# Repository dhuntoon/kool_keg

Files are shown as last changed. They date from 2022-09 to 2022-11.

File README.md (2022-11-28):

# Kool Keg
Purdue University > ECE Senior Design (ECE 49022) > Lab Section 5 > Team 51

This repository holds relevant files for Team 51 (_Kool Keg_) in ECE Senior Design. It includes hardware schematics, PCB layouts, mobile application software, and software diagrams.

## Table of Contents

kool_keg (repository home directory)

* `/Circuit Design/...`
  * system hardware schematics
  
* `/main/...`
  * Software for MCU
 
* `/Kool Keg Circuit/...`
  * PCB Design and related files for system hardware

* `/Software/...`
  * Software subsystem working directory
  * `/aws_backend/...`
    * sub-directory contianing AWS Lambda code . 
    * This code is mirrored manually for reference and is **not** executed directly from this source.
    * **This directory holds code written by Dylan Huntoon for the subsystem**
  * `/figures/`...
    * sub-directory containing software flow diagrams and subsystem block diagram(s)
    * **This directory holds figures created by Dylan Huntoon for the subsystem**
  * `/keg_app/...`
    * sub-directory containing code related to the mobile app (Flutter SDK and dependencies)
    * `/lib/...`
      * sub-directory containing Flutter (Dart) code for the mobile app
      * **This directory holds code written by Dylan Huntoon for the subsystem**
  * `/testing_scripts/...` 
    * sub-directory containing Python code and JSON output for testing the software_subsystem
    * **This directory holds code written by Dylan Huntoon for the subsystem**
 
* `/README.md`
  * this markdown file

## Software Design

### Subsystem Block Diagram
The following diagram illustrates the components of the software subsystem and related interactions with other subsystems. The color-coding corresponds to the overall system diagram, found in the design documentation.

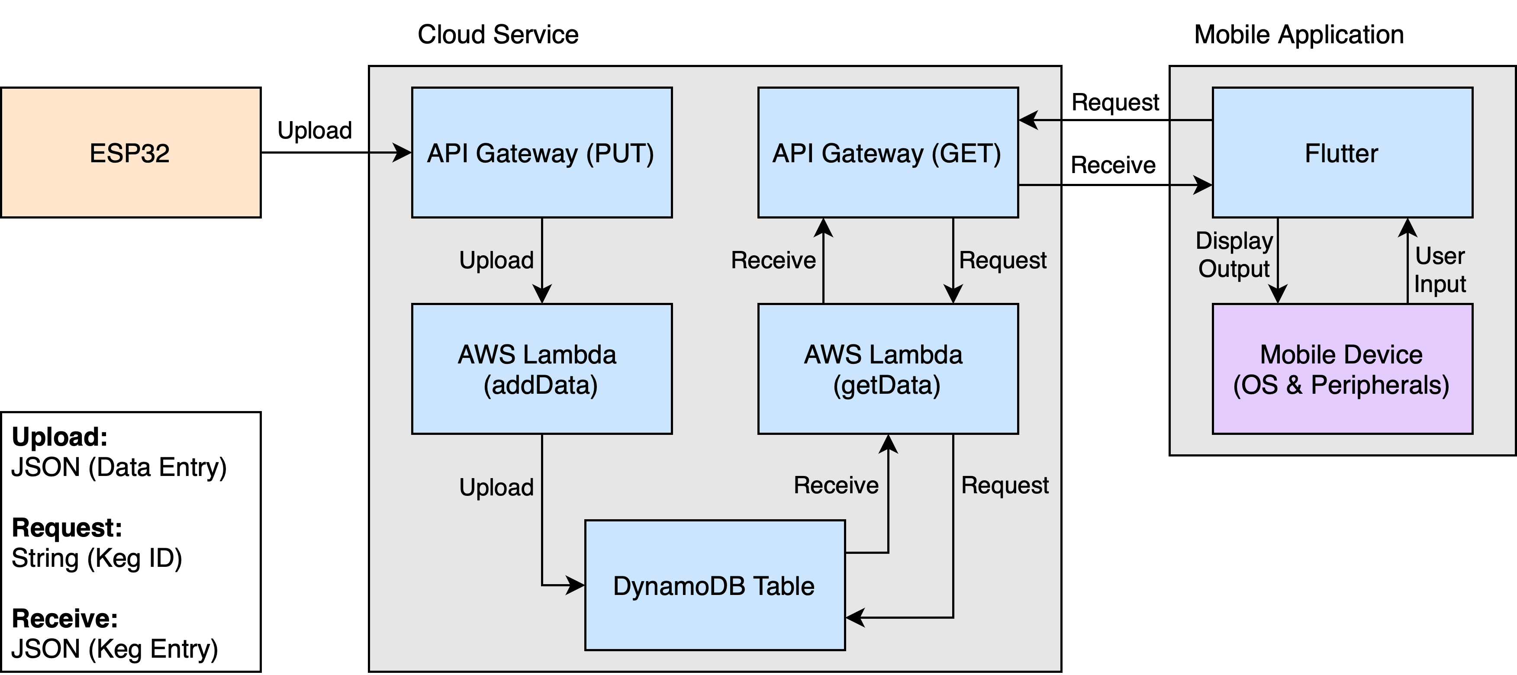
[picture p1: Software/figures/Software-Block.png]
Block Diagram


### Subsystem Software Architecture
The following diagram illustrates the software architecture for the system's mobile application. The program is written in Flutter (Dart) and is deployable on iOS and Android platforms. The black circle identifies the program entry point and is triggered when the application launches. 

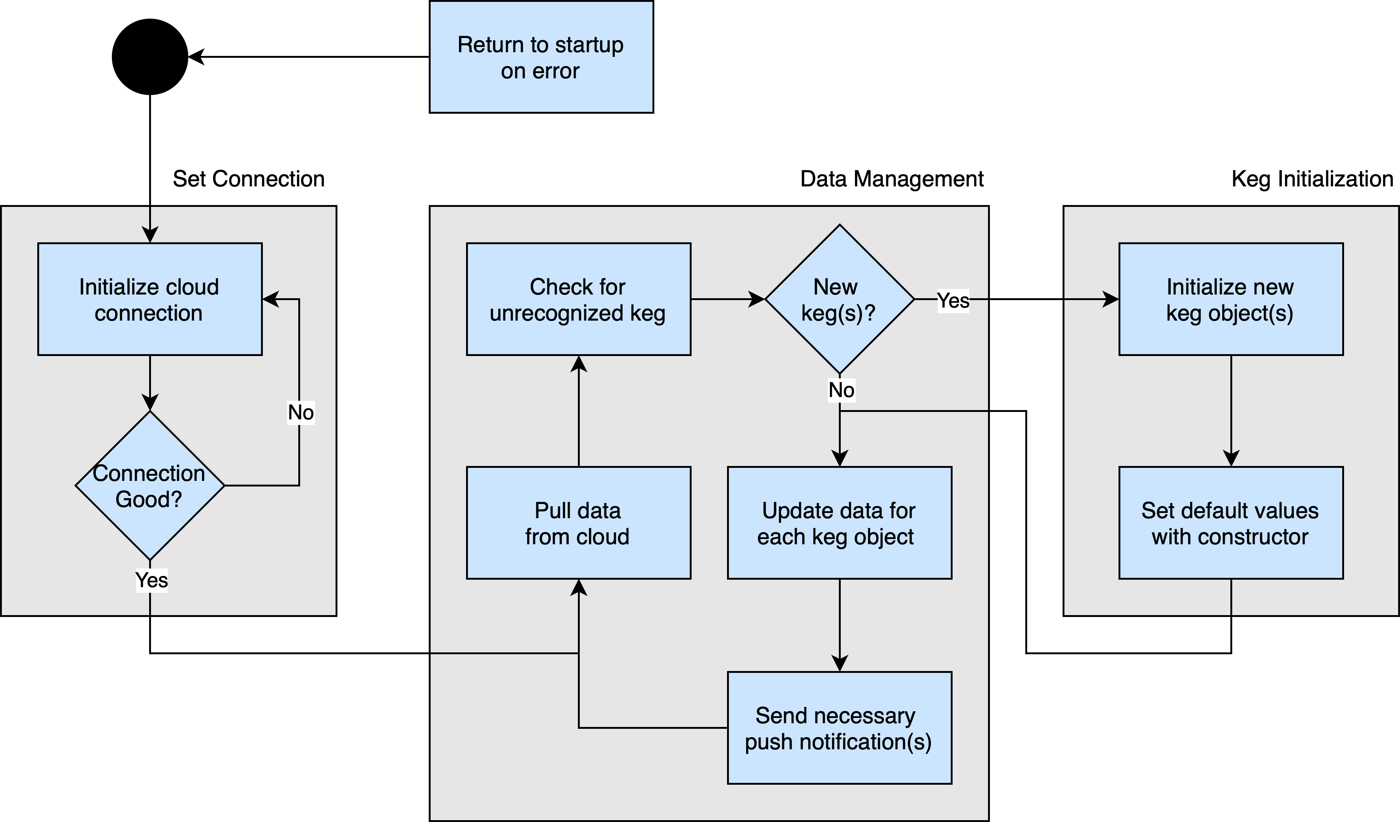
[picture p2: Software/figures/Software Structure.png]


For further detail, see the related figures in the `Software/figures/` subdirectory.

## Operating the Mobile App

Updated Nov 1, 2022.

The mobile application will be deployed onto devices supporting the iOS and Android platforms. Execution will automatically begin when the application is launched on the aforementioned devices.

To build or prototype with the program on a local machine, you must install the following dependencies. To ensure dependencies are installed correctly, reference the flutter documentation (https://docs.flutter.dev/get-started/install).

Dependencies:
* Flutter (Flutter SDK 3.3.1)
* Android toolchain (Android SDK version 33.0.0)
* Xcode (Xcode 14.0) - for building and emulating iOS applications
* Android Studio (version 2021.2) - for emulating Android applications

For rapid prototyping and testing, an IDE (such as VSCode or XCode) is recommended. Alternative command line operations are listed below for Unix terminals. 

### Command Line Operations

See the following documentation for Flutter Command Line Tools: https://docs.flutter.dev/reference/flutter-cli.

```$ flutter --version``` returns the version of flutter installed on your machine. 

```$ flutter doctor``` returns the dependency checks for the aforementioned libraries. Helpful installation directions are provided for missing dependencies. 

To build the program:
```
$ cd kool_keg/Software/keg_app
$ flutter build target
```
where `target` is the targeted platform (ios, android, etc.)

To run the program:
```
$ cd kool_keg/Software/keg_app
$ flutter run lib/main.dart
```

## Credits

Contributors to this repository:
* Cole Kniffen (ckniffen@purdue.edu)
* Dylan Huntoon (dhuntoon@purdue.edu)
* Mitchell Morris (morri448@purdue.edu)
* Jared Nutt (nuttj@purdue.edu)

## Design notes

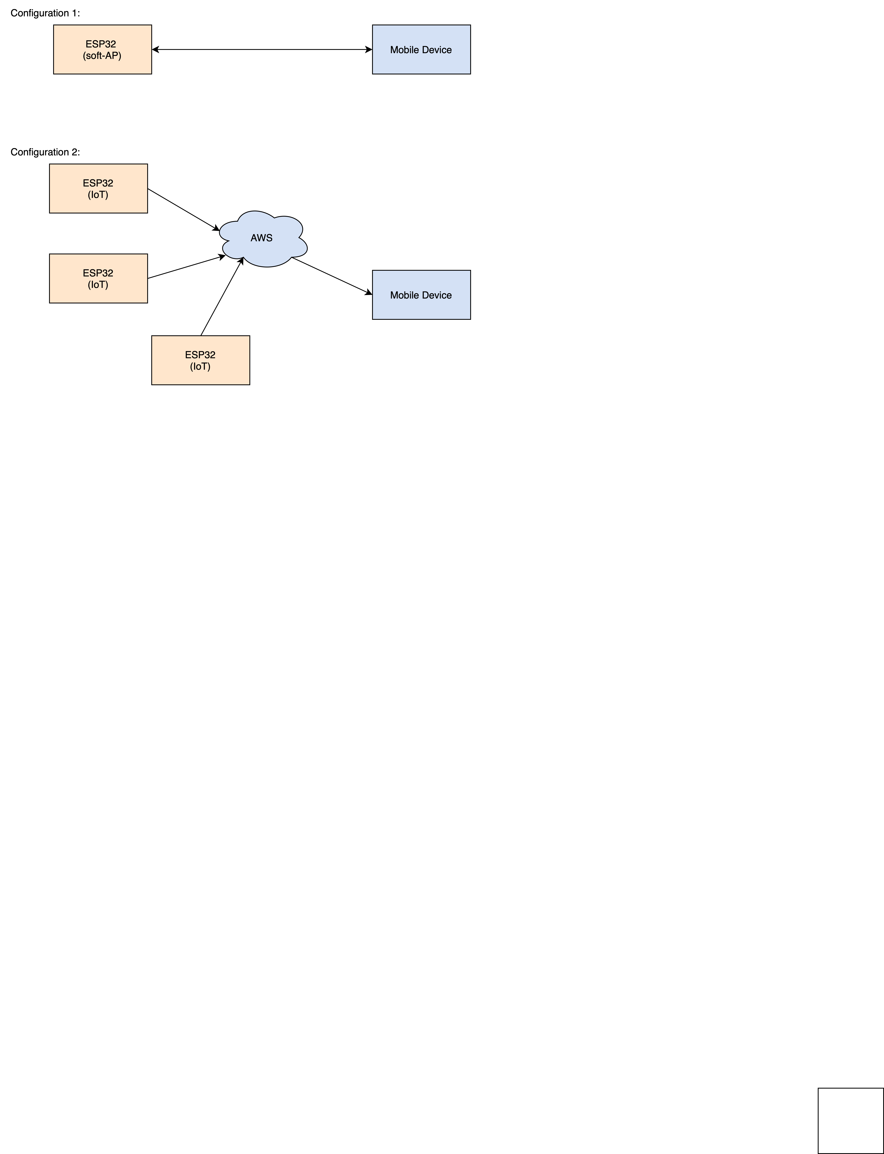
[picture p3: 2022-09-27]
Software/design/cloud_vs_direct_ configs.png

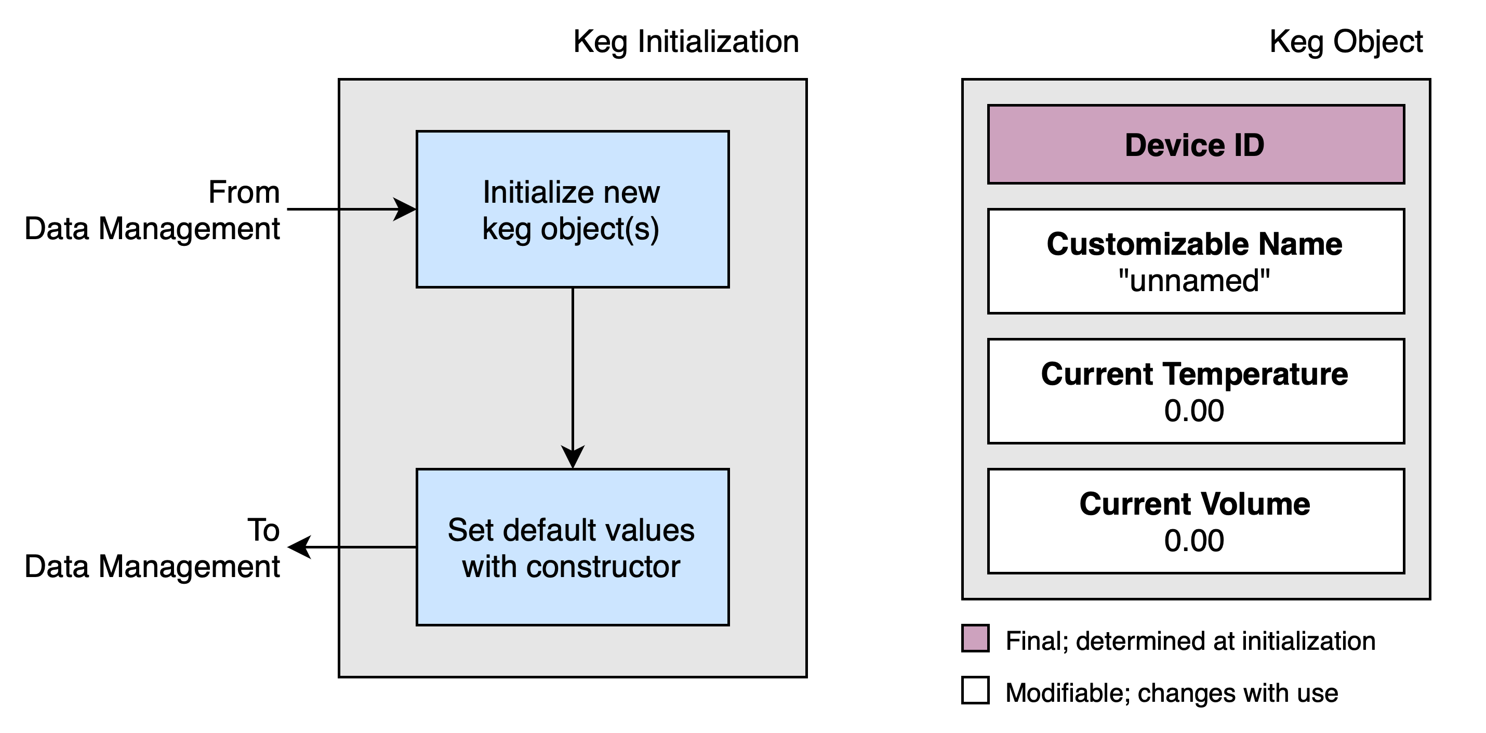
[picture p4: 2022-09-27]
Software/design/Object Structure.png

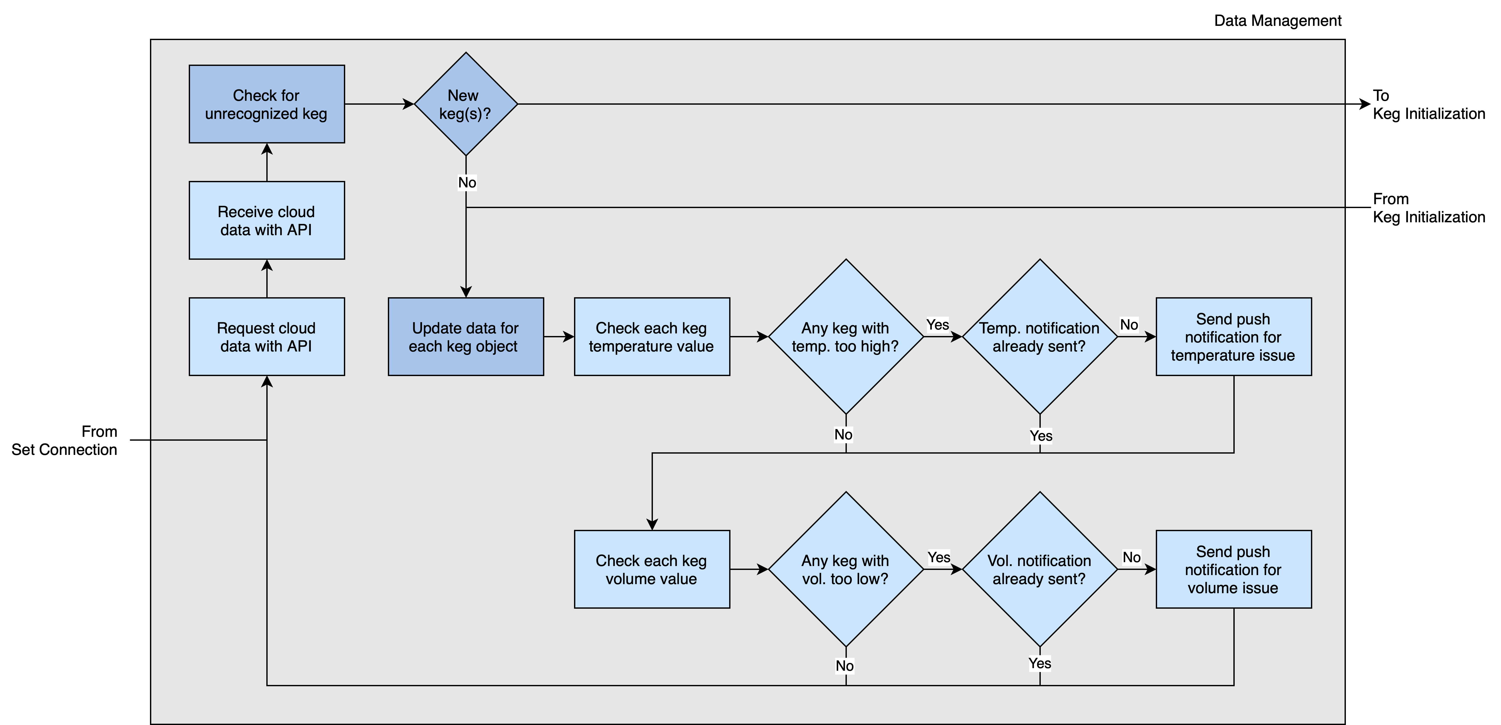
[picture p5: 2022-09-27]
Software/design/Data Management.png

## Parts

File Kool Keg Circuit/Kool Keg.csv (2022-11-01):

Source: | /Users/ckniffen/Desktop/Senior Design/kool_keg/Kool Keg Circuit/Kool Keg.kicad_sch
Date: | Tuesday, November 01, 2022 at 11:46:51 AM
Tool: | Eeschema (6.0.7-1)-1
Generator: | /Applications/KiCad/KiCad.app/Contents/SharedSupport/plugins/bom_csv_grouped_by_value_with_fp.py
Component Count: | 68
Ref | Qnty | Value | Cmp name | Footprint | Description | Vendor
C1, | 1 | 100nF | C | Capacitor_SMD:C_0805_2012Metric_Pad1.18x1.45mm_HandSolder | Unpolarized capacitor
C2, | 1 | 10uF | C | Capacitor_SMD:CP_Elec_4x5.8 | Unpolarized capacitor
C3, | 1 | 68nF | C | Capacitor_SMD:C_0805_2012Metric_Pad1.18x1.45mm_HandSolder | Unpolarized capacitor
C4, C5, C15, C17, | 4 | 10uF | CAP | Capacitor_SMD:C_0805_2012Metric_Pad1.18x1.45mm_HandSolder | Capacitor symbol for simulation only
C6, | 1 | .1uF | C | Capacitor_SMD:C_0603_1608Metric_Pad1.08x0.95mm_HandSolder | Unpolarized capacitor
C7, | 1 | 100uF | C | Capacitor_SMD:CP_Elec_6.3x5.8 | Unpolarized capacitor
C8, | 1 | 56pF | C | Capacitor_SMD:C_0603_1608Metric_Pad1.08x0.95mm_HandSolder | Unpolarized capacitor
C9, C10, C22, | 3 | 22uF | C_Small | Capacitor_SMD:C_0805_2012Metric_Pad1.18x1.45mm_HandSolder | Unpolarized capacitor, small symbol
C11, C12, C13, C14, C16, C23, | 6 | 0.1uF | C_Small | Capacitor_SMD:C_0805_2012Metric_Pad1.18x1.45mm_HandSolder | Unpolarized capacitor, small symbol
C18, | 1 | 2.2uF | C_Small | Capacitor_SMD:C_0805_2012Metric_Pad1.18x1.45mm_HandSolder | Unpolarized capacitor, small symbol
C19, C21, | 2 | .1uF | C_Small | Capacitor_SMD:C_0805_2012Metric_Pad1.18x1.45mm_HandSolder | Unpolarized capacitor, small symbol
C20, | 1 | 100 nF | C_Small | Capacitor_SMD:C_0805_2012Metric_Pad1.18x1.45mm_HandSolder | Unpolarized capacitor, small symbol
D1, D2, D3, | 3 | D | D | Diode_SMD:D_0805_2012Metric_Pad1.15x1.40mm_HandSolder | Diode
D4, | 1 | 1N4148 | 1N4148 | Diode_THT:D_DO-35_SOD27_P7.62mm_Horizontal | 100V 0.15A standard switching diode, DO-35
J1, | 1 | Conn_01x02_Male | Conn_01x02_Male | Connector_Molex:Molex_KK-396_A-41791-0002_1x02_P3.96mm_Vertical | Generic connector, single row, 01x02, script generated (kicad-library-utils/schlib/autogen/connector/)
J2, | 1 | Scale Header | Conn_01x04_Male | Connector_PinHeader_2.00mm:PinHeader_1x04_P2.00mm_Vertical | Generic connector, single row, 01x04, script generated (kicad-library-utils/schlib/autogen/connector/)
J3, | 1 | IR Header | Conn_01x04_Male | Connector_PinHeader_2.00mm:PinHeader_1x04_P2.00mm_Vertical | Generic connector, single row, 01x04, script generated (kicad-library-utils/schlib/autogen/connector/)
J4, | 1 | Flowmeter Header | Conn_01x03_Male | Connector_PinHeader_2.00mm:PinHeader_1x03_P2.00mm_Vertical | Generic connector, single row, 01x03, script generated (kicad-library-utils/schlib/autogen/connector/)
J5, | 1 | Prog | Conn_01x06_Male | Connector_PinHeader_2.00mm:PinHeader_1x06_P2.00mm_Vertical | Generic connector, single row, 01x06, script generated (kicad-library-utils/schlib/autogen/connector/)
J6, | 1 | Solenoid Conn, 01x02_Male | Conn_01x02_Male | Connector_Molex:Molex_KK-396_A-41791-0002_1x02_P3.96mm_Vertical | Generic connector, single row, 01x02, script generated (kicad-library-utils/schlib/autogen/connector/)
J7, | 1 | Conn_01x02_Female | Conn_01x04_Female | Connector_PinHeader_2.00mm:PinHeader_1x04_P2.00mm_Vertical | Generic connector, single row, 01x04, script generated (kicad-library-utils/schlib/autogen/connector/)
L1, | 1 | 3.3uH | L | Inductor_SMD:L_Bourns_SRN6045TA | Inductor
Q1, | 1 | 2N3905 | 2N3905 | Package_TO_SOT_THT:TO-92_Inline | -0.2A Ic, -40V Vce, Small Signal PNP Transistor, TO-92
Q2, | 1 | 2N3906 | 2N3906 | Package_TO_SOT_THT:TO-92_Inline | -0.2A Ic, -40V Vce, Small Signal PNP Transistor, TO-92
R1, | 1 | 330 | R | Resistor_SMD:R_0805_2012Metric_Pad1.20x1.40mm_HandSolder | Resistor
R2, | 1 | 1k | R | Resistor_SMD:R_0805_2012Metric_Pad1.20x1.40mm_HandSolder | Resistor
R3, | 1 | 30.9k | R | Resistor_SMD:R_0805_2012Metric_Pad1.20x1.40mm_HandSolder | Resistor
R4, R16, R17, R18, R19, R20, R21, | 7 | 10k | R | Resistor_SMD:R_0805_2012Metric_Pad1.20x1.40mm_HandSolder | Resistor
R5, R6, R7, R8, R9, R10, | 6 | 22000 | R | Resistor_SMD:R_0805_2012Metric_Pad1.20x1.40mm_HandSolder | Resistor
R11, R12, | 2 | 100 | R | Resistor_SMD:R_0805_2012Metric_Pad1.20x1.40mm_HandSolder | Resistor
R13, | 1 | 8.2k | R | Resistor_SMD:R_0805_2012Metric_Pad1.20x1.40mm_HandSolder | Resistor
R14, | 1 | 22k | R | Resistor_SMD:R_0805_2012Metric_Pad1.20x1.40mm_HandSolder | Resistor
R15, | 1 | 100k | R_Small | Resistor_SMD:R_0805_2012Metric_Pad1.20x1.40mm_HandSolder | Resistor, small symbol
SW1, SW2, SW3, | 3 | SW_MEC_5G | SW_Push | Button_Switch_THT:SW_PUSH-12mm | Push button switch, generic, two pins
U1, | 1 | LM1117-ADJ | LM1117-ADJ | Package_TO_SOT_SMD:SOT-223-3_TabPin2 | 800mA Low-Dropout Linear Regulator, adjustable output, TO-220/TO-252/TO-263/SOT-223
U2, | 1 | TPS562207 | TPS562200 | Package_TO_SOT_SMD:SOT-563 | 2A Synchronous Step-Down Voltage Regulator, Adjustable Output Voltage, 4.5-17V Input Voltage, SOT-23-6
U3, | 1 | 74LVC3G14 | 74LVC3G14 | Package_SO:MSOP-8_3x3mm_P0.65mm | Triple NOT Gate Schmitt, Low-Voltage CMOS
U4, | 1 | HX711 | HX711_1 | Package_SO:SOP-16_3.9x9.9mm_P1.27mm
U5, | 1 | 946-MPQ6610GS-AEC1-P | 946-MPQ6610GS-AEC1-P | Package_SO:SOIC-8_3.9x4.9mm_P1.27mm
U6, | 1 | 24LC256-I/MS | 24LC256 | Package_SO:MSOP-8_3x3mm_P0.65mm | I2C Serial EEPROM, 256Kb, DIP-8/SOIC-8/TSSOP-8/DFN-8
U7, | 1 | ESP32-WROOM-32D | ESP32-WROOM-32D | RF_Module:ESP32-WROOM-32 | RF Module, ESP32-D0WD SoC, Wi-Fi 802.11b/g/n, Bluetooth, BLE, 32-bit, 2.7-3.6V, onboard antenna, SMD

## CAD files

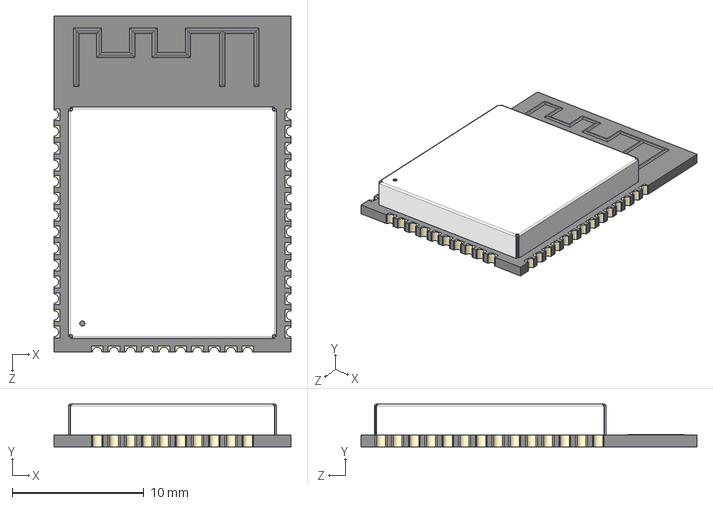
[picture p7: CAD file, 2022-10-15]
Kool Keg Circuit/ESP32-WROOM-32D/ESP32-WROOM-32D.step
18.0 x 3.25 x 25.5 mm

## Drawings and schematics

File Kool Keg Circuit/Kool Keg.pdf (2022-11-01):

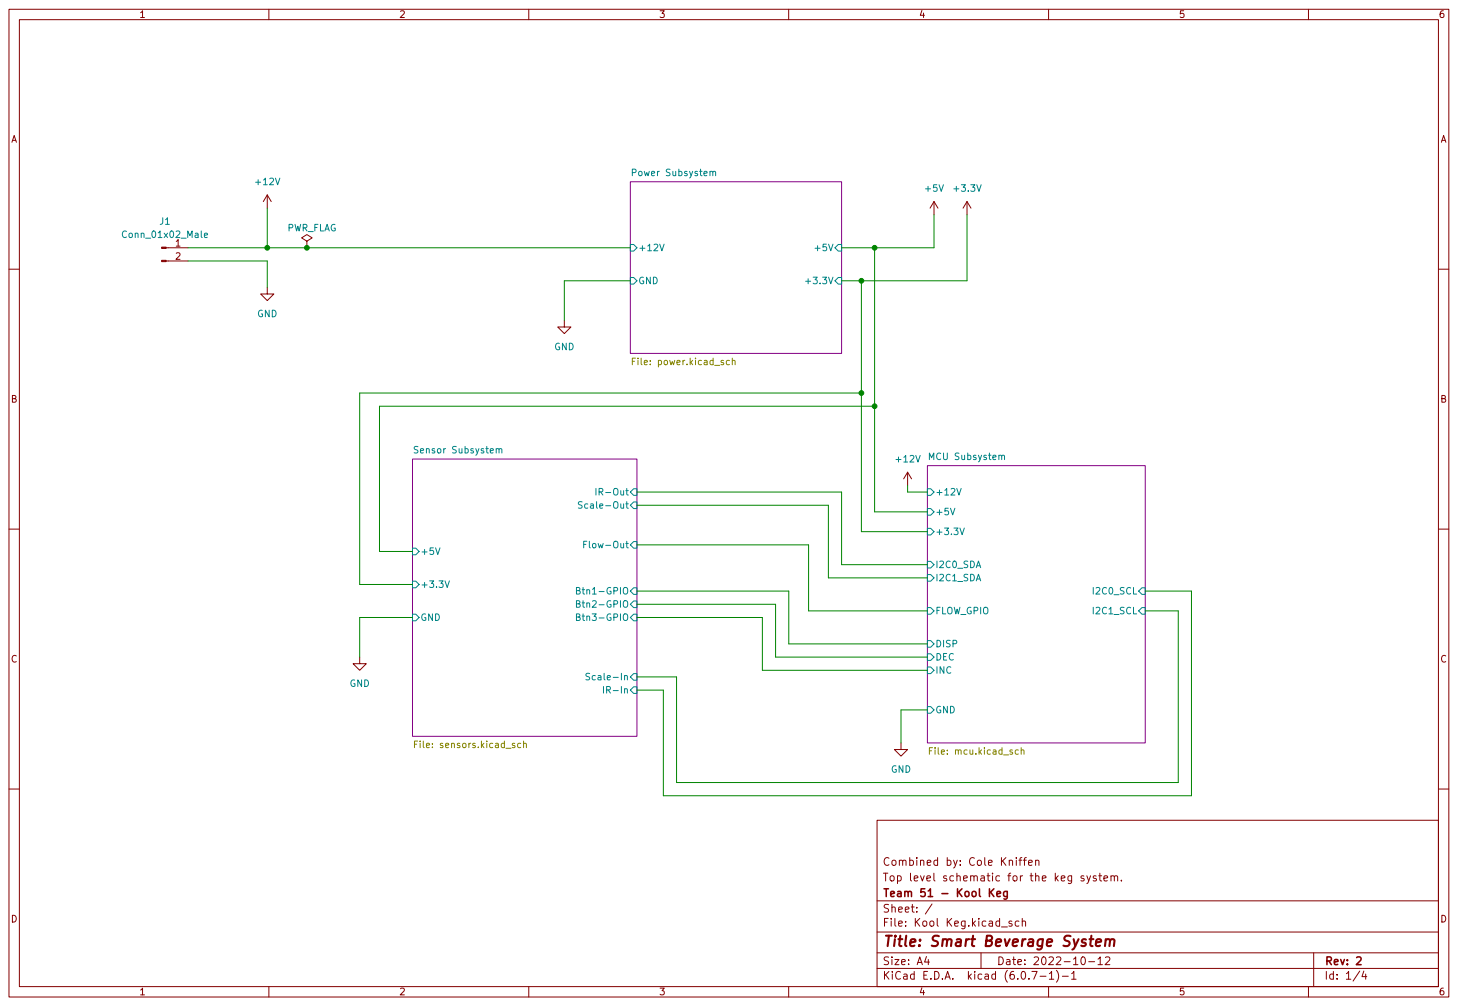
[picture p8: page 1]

Scale-Out Scale-In Sensor Subsystem

IR-Out Flow-Out Btn1-GPIO

Combined by: Cole Kniffen
Top level schematic for the keg system.
File: Kool Keg.kicad_sch Sheet: / Team 51 - Kool Keg

Id: 1/4 Title: Smart Beverage System

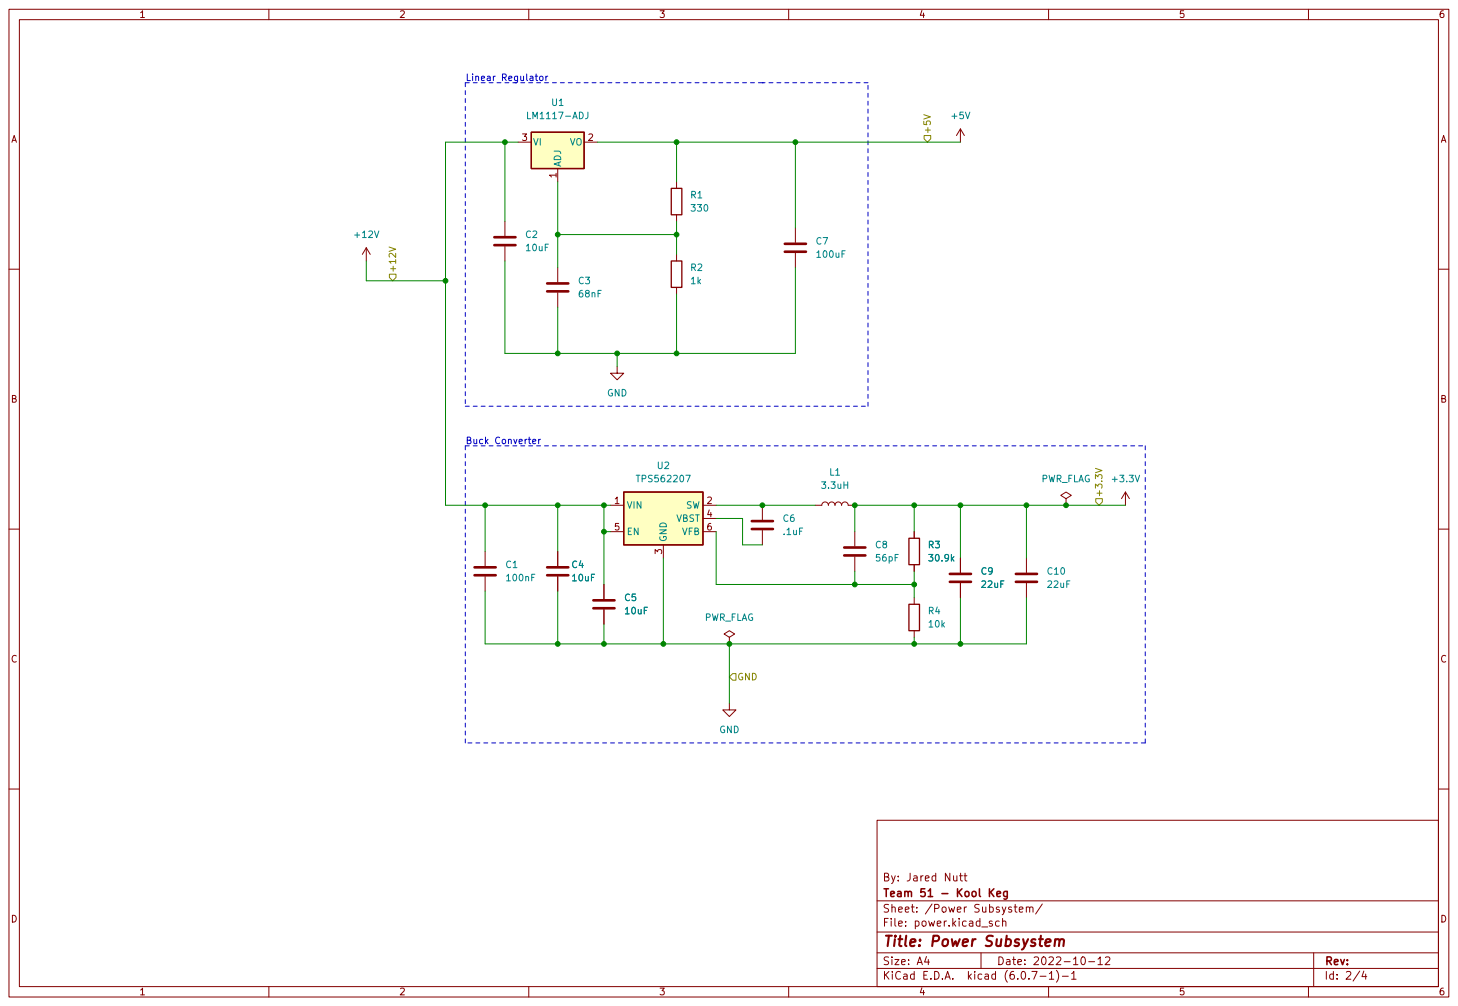
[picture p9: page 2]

Team 51 - Kool Keg
Sheet: /Power Subsystem/
File: power.kicad_sch
Id: 2/4 Title: Power Subsystem

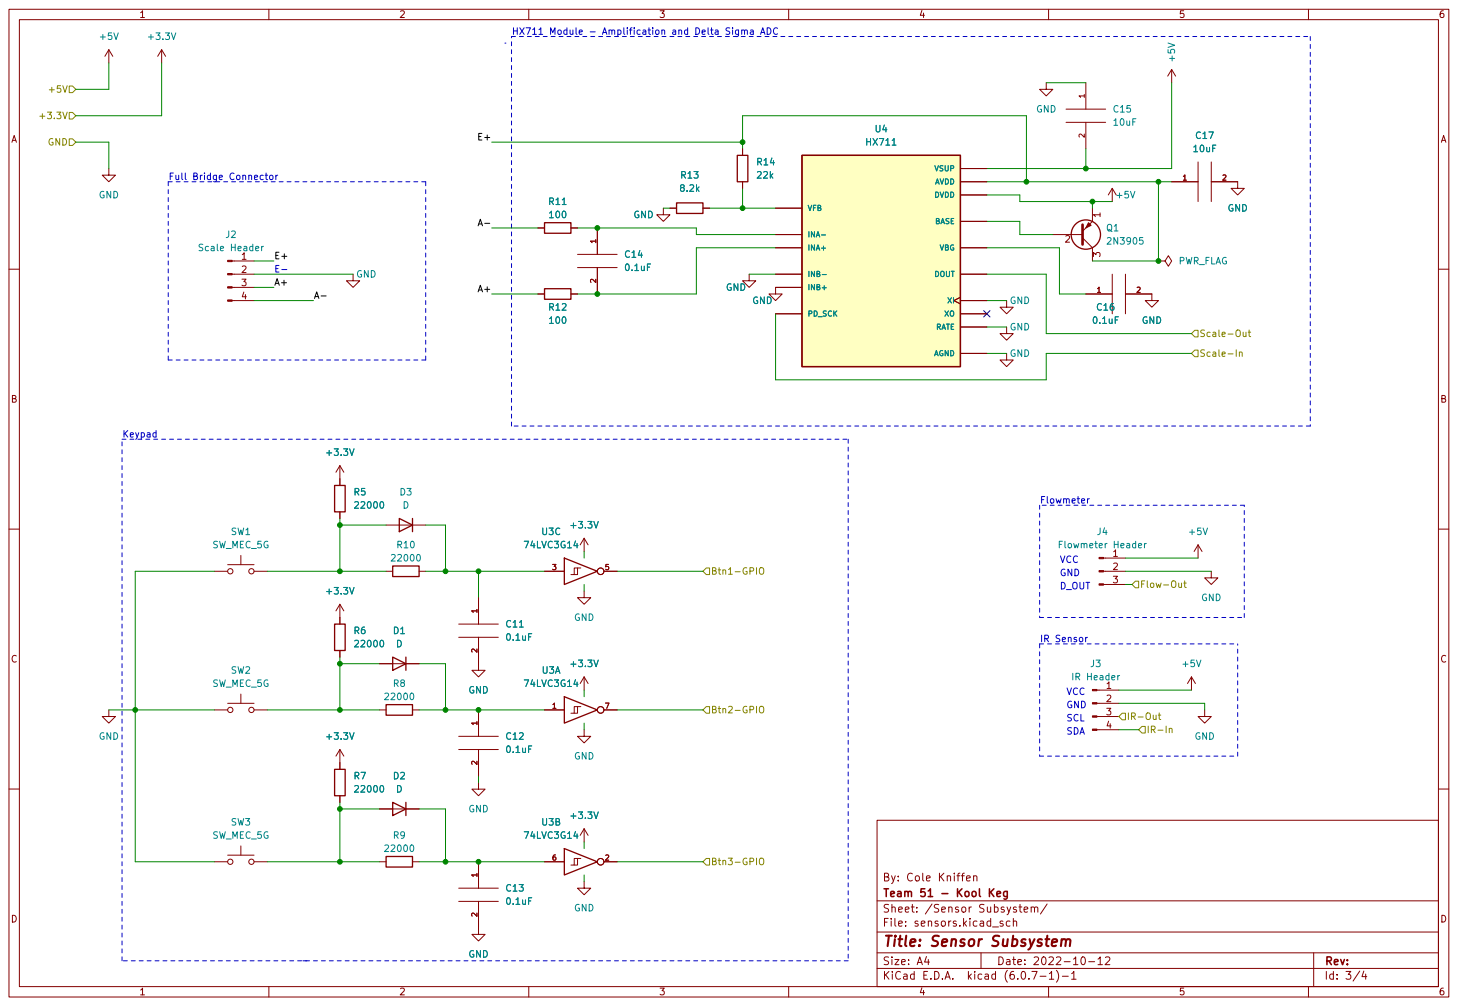
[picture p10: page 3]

HX711 Module - Amplification and Delta Sigma ADC

By: Cole Kniffen
Team 51 - Kool Keg
Sheet: /Sensor Subsystem/
File: sensors.kicad_sch
Id: 3/4 Title: Sensor Subsystem

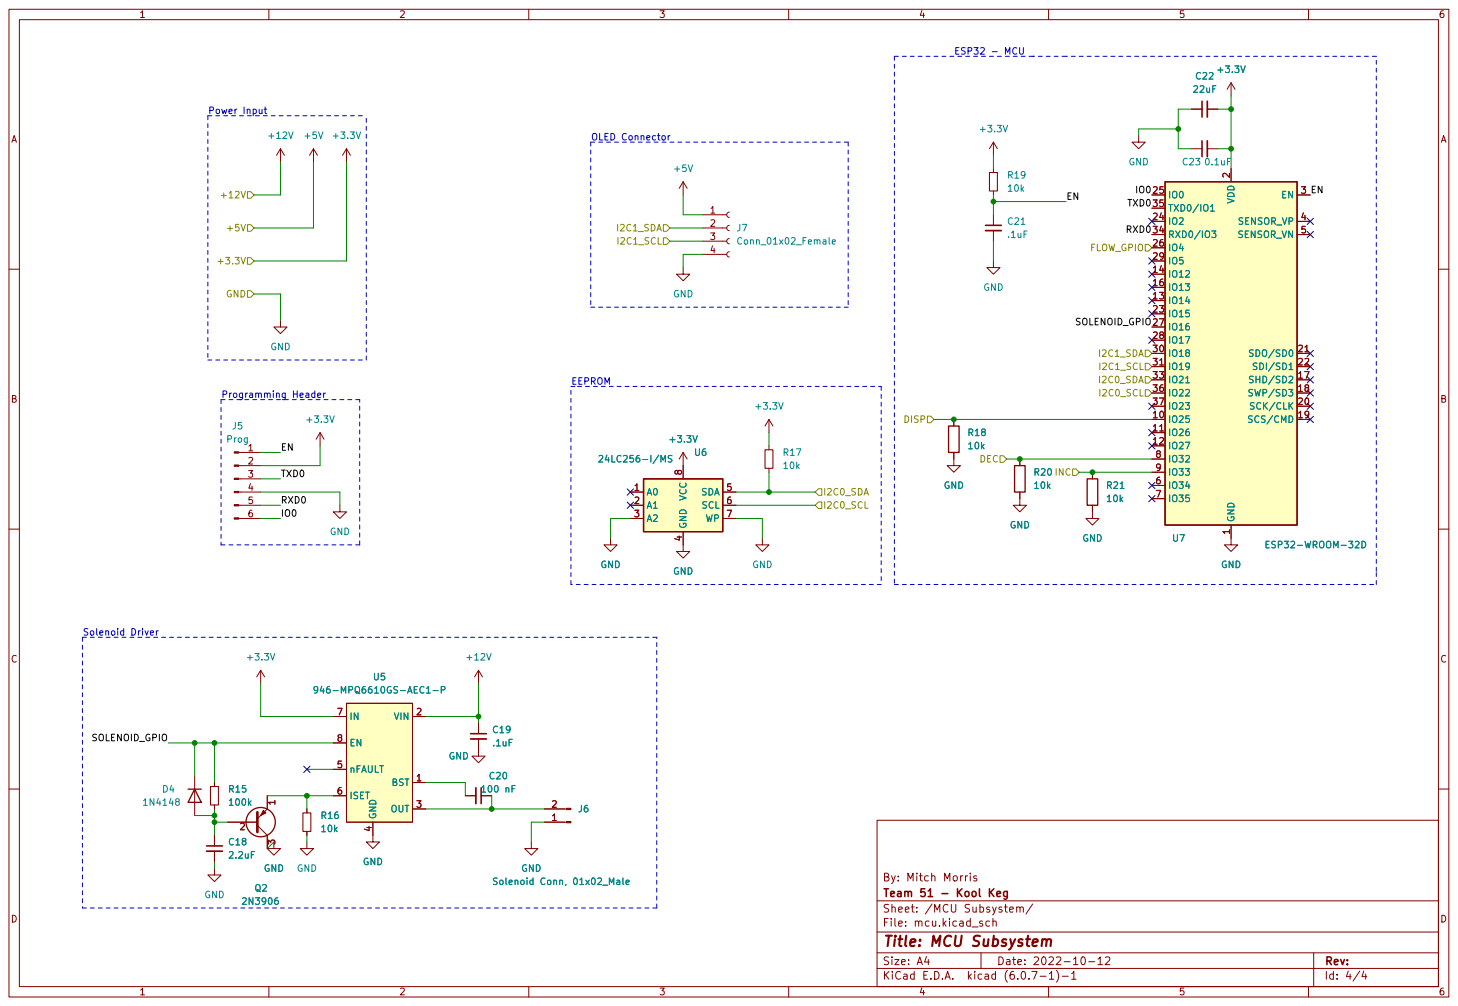
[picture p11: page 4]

2 SCK/CLK 20 SDO/SD0 21 SDI/SD1 22

4 SDA 5 SCL 6 WP 7 VCC

Team 51 - Kool Keg
Sheet: /MCU Subsystem/
File: mcu.kicad_sch
Id: 4/4 Title: MCU Subsystem

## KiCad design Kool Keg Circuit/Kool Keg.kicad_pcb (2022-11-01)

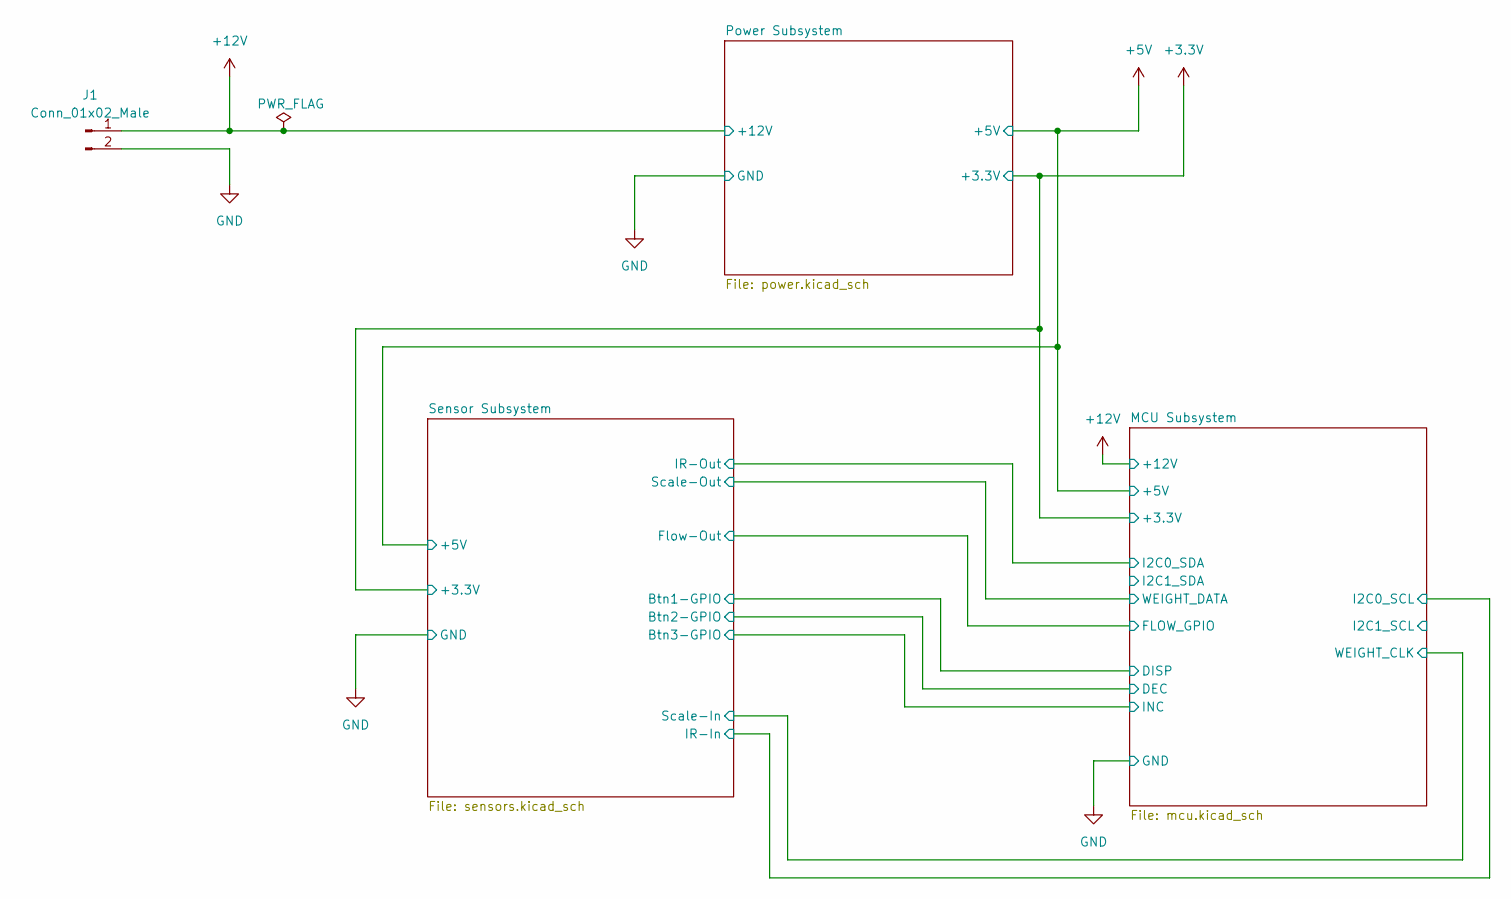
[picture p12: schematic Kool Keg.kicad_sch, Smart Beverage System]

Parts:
J1: Conn_01x02_Male; Molex_KK-396_A-41791-0002_1x02_P3.96mm_Vertical

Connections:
+12V: J1.1; also elsewhere on the board
GND: J1.2; also elsewhere on the board

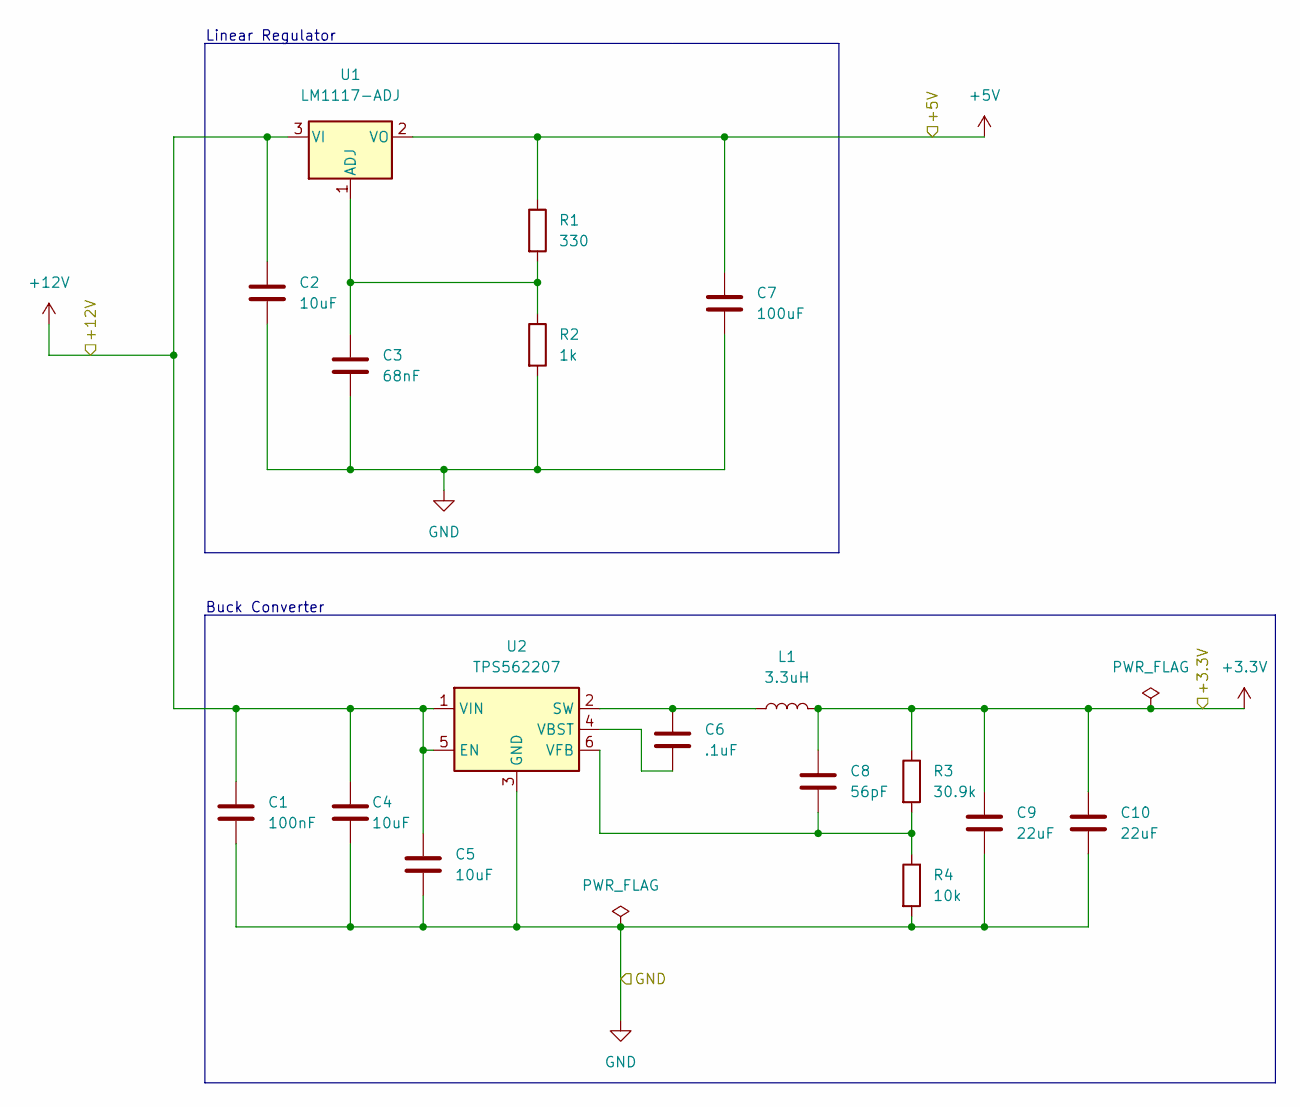
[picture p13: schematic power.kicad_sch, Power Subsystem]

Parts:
C1: 100nF; C_0805_2012Metric_Pad1.18x1.45mm_HandSolder
C2: 10uF; CP_Elec_4x5.8
C3: 68nF; C_0805_2012Metric_Pad1.18x1.45mm_HandSolder
C4, C5: 10uF; C_0805_2012Metric_Pad1.18x1.45mm_HandSolder
C6: .1uF; C_0805_2012Metric_Pad1.18x1.45mm_HandSolder
C7: 100uF; CP_Elec_6.3x5.8
C8: 56pF; C_0603_1608Metric_Pad1.08x0.95mm_HandSolder
C9, C10: 22uF; C_0805_2012Metric_Pad1.18x1.45mm_HandSolder
L1: 3.3uH; L_Bourns_SRN6045TA
R1: 330; R_0805_2012Metric_Pad1.20x1.40mm_HandSolder
R2: 1k; R_0805_2012Metric_Pad1.20x1.40mm_HandSolder
R3: 30.9k; R_0805_2012Metric_Pad1.20x1.40mm_HandSolder
R4: 10k; R_0805_2012Metric_Pad1.20x1.40mm_HandSolder
U1: LM1117-ADJ; SOT-223-3_TabPin2
U2: TPS562207; SOT-563

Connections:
+3.3V: C8.1, C9.1, C10.1, L1.2, R3.1; also elsewhere on the board
+5V: C7.1, R1.1, U1.2 (VO); also elsewhere on the board
+12V: C1.1, C2.1, C4.1, C5.1, U1.3 (VI), U2.1 (VIN), U2.5 (EN); also elsewhere on the board
GND: C1.2, C2.2, C3.2, C4.2, C5.2, C7.2, C9.2, C10.2, R2.2, R4.2, U2.3 (GND); also elsewhere on the board
unnamed: C3.1, R1.2, R2.1, U1.1 (ADJ)
unnamed: C6.1, L1.1, U2.2 (SW)
unnamed: C6.2, U2.4 (VBST)
unnamed: C8.2, R3.2, R4.1, U2.6 (VFB)

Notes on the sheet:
Buck Converter
Linear Regulator

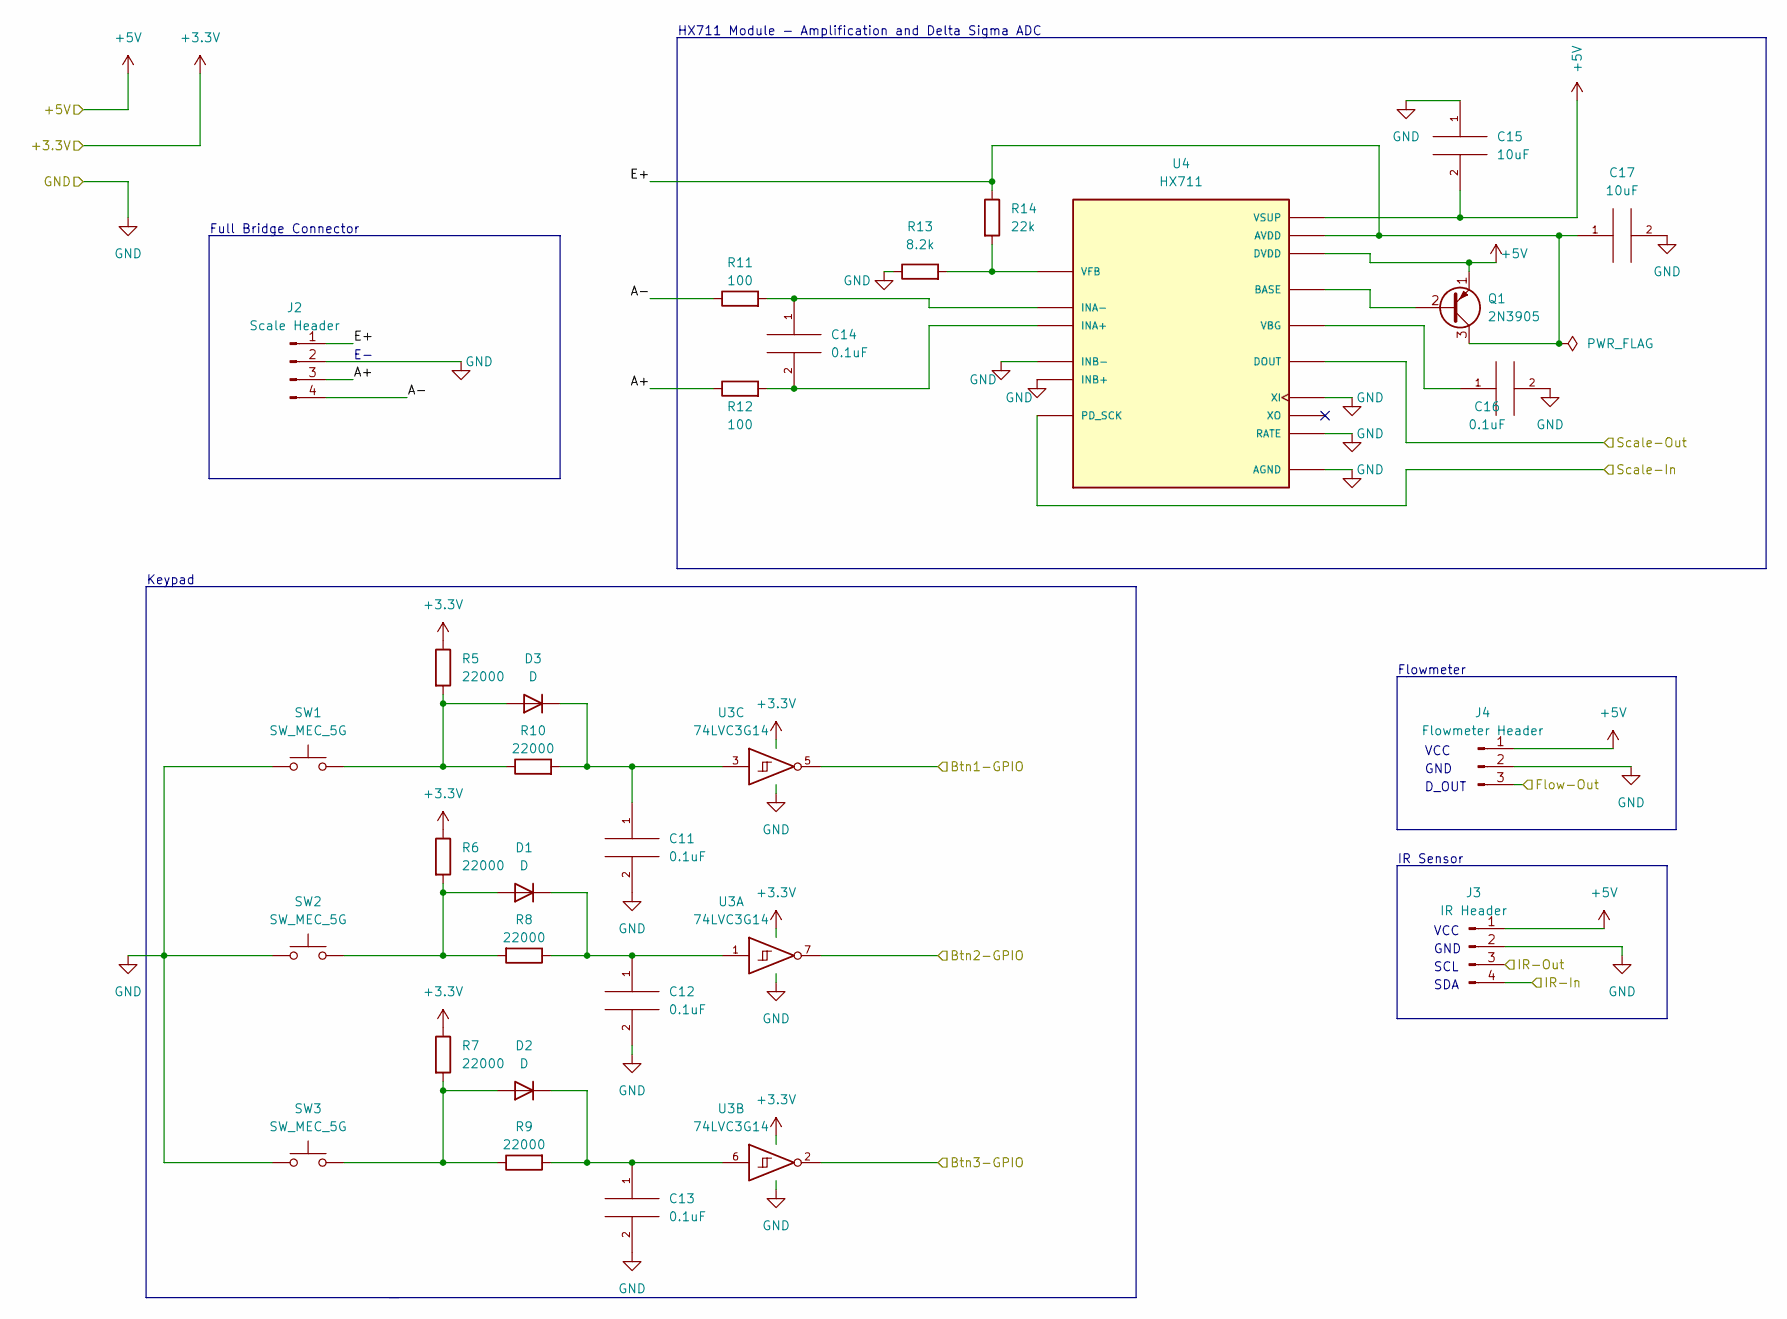
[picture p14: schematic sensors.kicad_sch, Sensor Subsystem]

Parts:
C11, C12, C13, C14, C16: 0.1uF; C_0805_2012Metric_Pad1.18x1.45mm_HandSolder
C15, C17: 10uF; C_0805_2012Metric_Pad1.18x1.45mm_HandSolder
D1, D2, D3: D; D_SOD-323_HandSoldering
J2: Scale Header; PinHeader_1x04_P2.00mm_Vertical
J3: IR Header; PinHeader_1x04_P2.00mm_Vertical
J4: Flowmeter Header; PinHeader_1x03_P2.00mm_Vertical
Q1: 2N3905; TO-92_Inline
R5, R6, R7, R8, R9, R10: 22000; R_0805_2012Metric_Pad1.20x1.40mm_HandSolder
R11, R12: 100; R_0805_2012Metric_Pad1.20x1.40mm_HandSolder
R13: 8.2k; R_0805_2012Metric_Pad1.20x1.40mm_HandSolder
R14: 22k; R_0805_2012Metric_Pad1.20x1.40mm_HandSolder
SW1, SW2, SW3: SW_MEC_5G; SW_PUSH-12mm
U3: 74LVC3G14; MSOP-8_3x3mm_P0.65mm
U4: HX711; SOP-16_3.9x9.9mm_P1.27mm; PARTREV V2.0

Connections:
+3.3V: R5.1, R6.1, R7.1, U3.8 (VCC); also elsewhere on the board
+5V: C15.2, J3.1, J4.1, Q1.1 (E), U4.1 (VSUP), U4.16 (DVDD); also elsewhere on the board
/MCU Subsystem/DEC: U3.7; also elsewhere on the board
/MCU Subsystem/DISP: U3.5; also elsewhere on the board
/MCU Subsystem/FLOW_GPIO: J4.3; also elsewhere on the board
/MCU Subsystem/I2C0_SCL: J3.4; also elsewhere on the board
/MCU Subsystem/I2C0_SDA: J3.3; also elsewhere on the board
/MCU Subsystem/INC: U3.2; also elsewhere on the board
/MCU Subsystem/WEIGHT_CLK: U4.11 (PD_SCK); also elsewhere on the board
/MCU Subsystem/WEIGHT_DATA: U4.12 (DOUT); also elsewhere on the board
/Sensor Subsystem/A+: J2.3, R12.1
/Sensor Subsystem/A-: J2.4, R11.1
/Sensor Subsystem/E+: C17.1, J2.1, Q1.3 (C), R14.1, U4.3 (AVDD)
GND: C11.2, C12.2, C13.2, C15.1, C16.2, C17.2, J2.2, J3.2, J4.2, R13.1, SW1.1, SW2.1, SW3.1, U3.4 (GND), U4.5 (AGND), U4.9 (INB-), U4.10 (INB+), U4.14 (XI), U4.15 (RATE); also elsewhere on the board
unnamed: C11.1, D3.1 (K), R10.2, U3.3
unnamed: C12.1, D1.1 (K), R8.1, U3.1
unnamed: C13.1, D2.1 (K), R9.2, U3.6
unnamed: C14.1, R11.2, U4.7 (INA-)
unnamed: C14.2, R12.2, U4.8 (INA+)
unnamed: C16.1, U4.6 (VBG)
unnamed: D1.2 (A), R6.2, R8.2, SW2.2
unnamed: D2.2 (A), R7.2, R9.1, SW3.2
unnamed: D3.2 (A), R5.2, R10.1, SW1.2
unnamed: Q1.2 (B), U4.2 (BASE)
unnamed: R13.2, R14.2, U4.4 (VFB)

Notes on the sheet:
IR Sensor
GND
D_OUT
VCC
Flowmeter
SDA
HX711 Module - Amplification and Delta Sigma ADC
Full Bridge Connector
SCL
Keypad

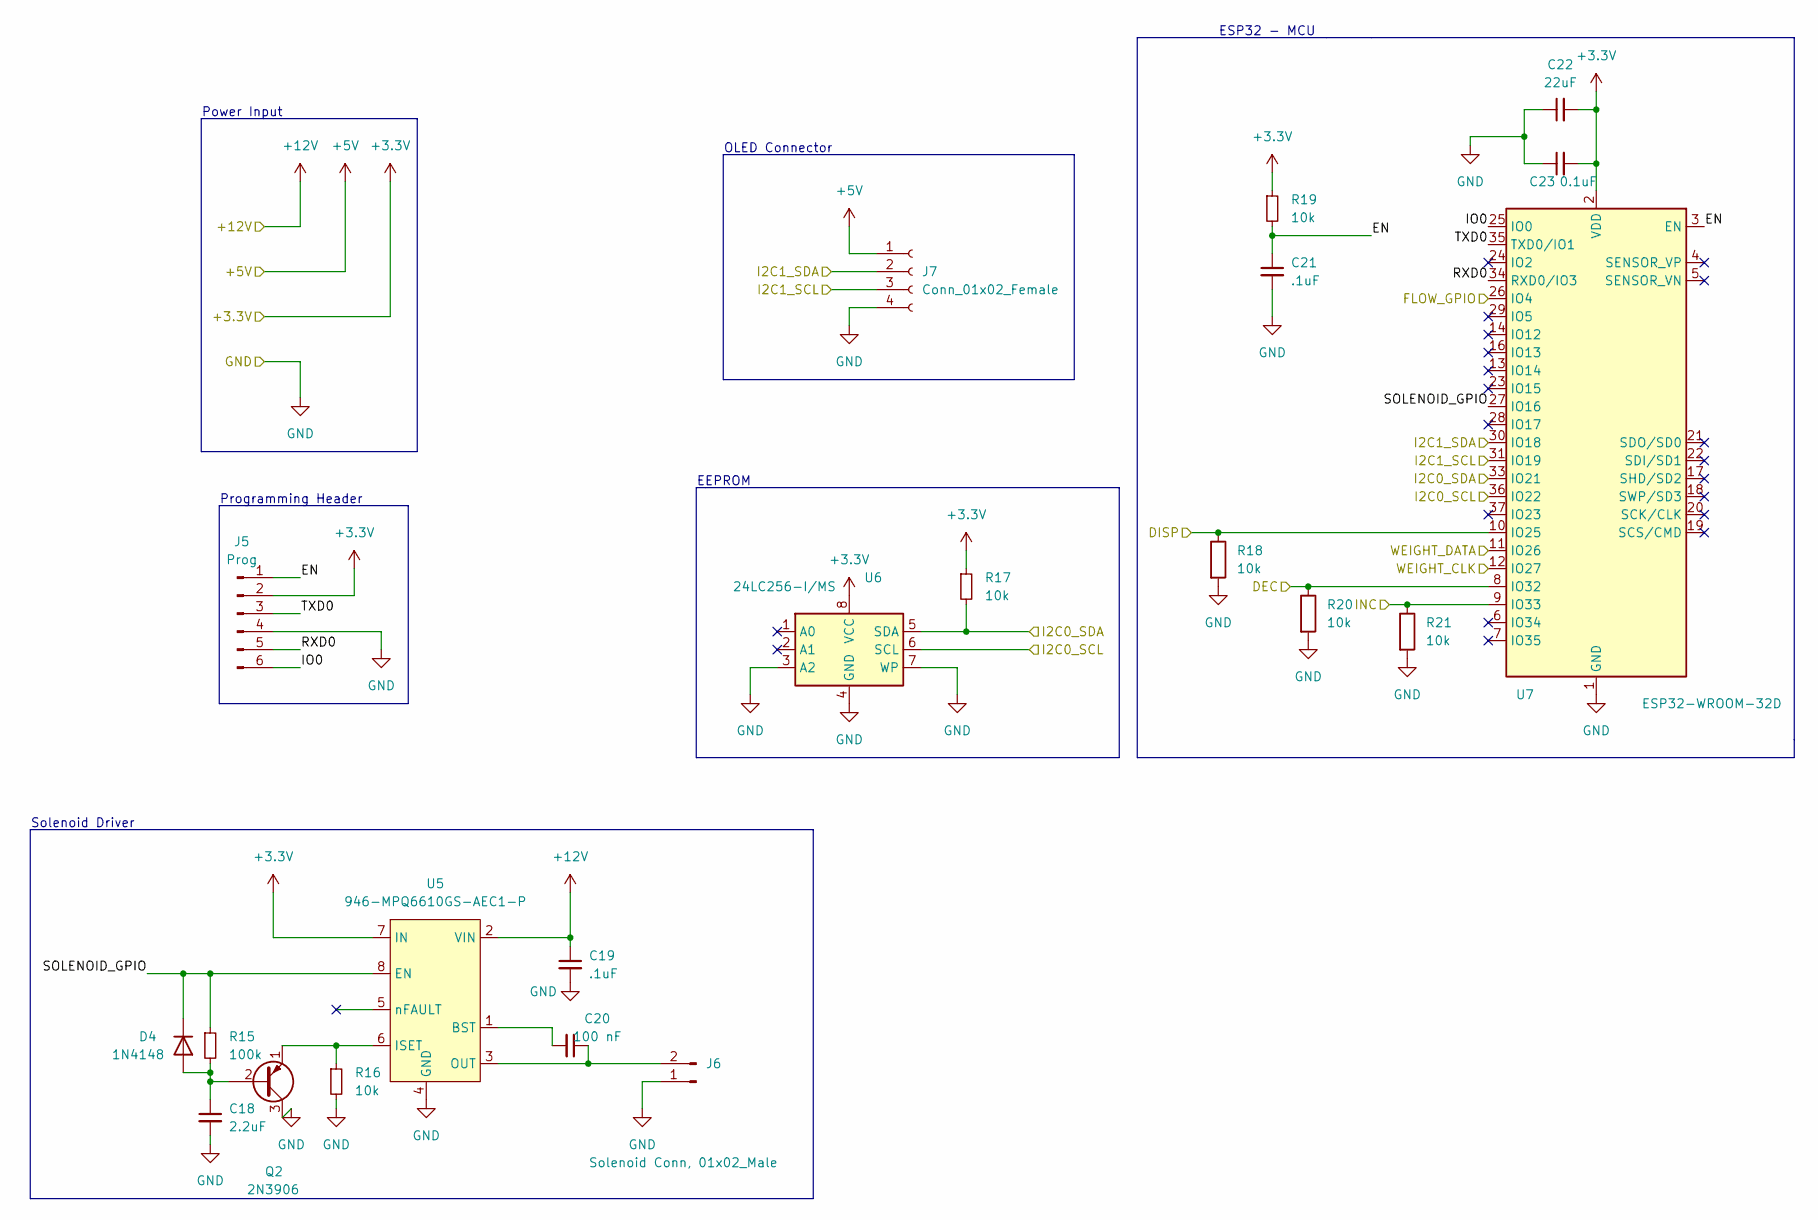
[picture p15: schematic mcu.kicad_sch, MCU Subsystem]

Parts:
C18: 2.2uF; C_0805_2012Metric_Pad1.18x1.45mm_HandSolder
C19, C21: .1uF; C_0805_2012Metric_Pad1.18x1.45mm_HandSolder
C20: 100 nF; C_0805_2012Metric_Pad1.18x1.45mm_HandSolder
C22: 22uF; C_0805_2012Metric_Pad1.18x1.45mm_HandSolder
C23: 0.1uF; C_0805_2012Metric_Pad1.18x1.45mm_HandSolder
D4: 1N4148; D_DO-35_SOD27_P7.62mm_Horizontal
J5: Prog; PinHeader_1x06_P2.00mm_Vertical
J6: Solenoid Conn, 01x02_Male; Molex_KK-396_A-41791-0002_1x02_P3.96mm_Vertical
J7: Conn_01x02_Female; PinHeader_1x04_P2.00mm_Vertical
Q2: 2N3906; TO-92_Inline
R15: 100k; R_0805_2012Metric_Pad1.20x1.40mm_HandSolder
R16, R17, R18, R19, R20, R21: 10k; R_0805_2012Metric_Pad1.20x1.40mm_HandSolder
U5: 946-MPQ6610GS-AEC1-P; SOIC-8_3.9x4.9mm_P1.27mm
U6: 24LC256-I/MS; MSOP-8_3x3mm_P0.65mm
U7: ESP32-WROOM-32D; ESP32-WROOM-32

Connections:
+3.3V: C22.2, C23.2, J5.2, R17.1, R19.1, U5.7 (IN), U6.8 (VCC), U7.2 (VDD); also elsewhere on the board
+5V: J7.1; also elsewhere on the board
+12V: C19.1, U5.2 (VIN); also elsewhere on the board
/MCU Subsystem/DEC: R20.1, U7.8 (IO32); also elsewhere on the board
/MCU Subsystem/DISP: R18.1, U7.10 (IO25); also elsewhere on the board
/MCU Subsystem/EN: C21.1, J5.1, R19.2, U7.3 (EN)
/MCU Subsystem/FLOW_GPIO: U7.26 (IO4); also elsewhere on the board
/MCU Subsystem/I2C0_SCL: U6.6 (SCL), U7.36 (IO22); also elsewhere on the board
/MCU Subsystem/I2C0_SDA: R17.2, U6.5 (SDA), U7.33 (IO21); also elsewhere on the board
/MCU Subsystem/I2C1_SCL: J7.3, U7.31 (IO19)
/MCU Subsystem/I2C1_SDA: J7.2, U7.30 (IO18)
/MCU Subsystem/INC: R21.1, U7.9 (IO33); also elsewhere on the board
/MCU Subsystem/IO0: J5.6, U7.25 (IO0)
/MCU Subsystem/RXD0: J5.5, U7.34 (RXD0/IO3)
/MCU Subsystem/SOLENOID_GPIO: D4.1 (K), R15.1, U5.8 (EN), U7.27 (IO16)
/MCU Subsystem/TXD0: J5.3, U7.35 (TXD0/IO1)
/MCU Subsystem/WEIGHT_CLK: U7.12 (IO27); also elsewhere on the board
/MCU Subsystem/WEIGHT_DATA: U7.11 (IO26); also elsewhere on the board
GND: C18.2, C19.2, C21.2, C22.1, C23.1, J5.4, J6.1, J7.4, Q2.3 (C), R16.2, R18.2, R20.2, R21.2, U5.4 (GND), U6.3 (A2), U6.4 (GND), U6.7 (WP), U7.1 (GND), U7.15 (GND), U7.38 (GND), U7.39 (GND); also elsewhere on the board
unnamed: C18.1, D4.2 (A), Q2.2 (B), R15.2
unnamed: C20.1, J6.2, U5.3 (OUT)
unnamed: C20.2, U5.1 (BST)
unnamed: Q2.1 (E), R16.1, U5.6 (ISET)

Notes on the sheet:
Solenoid Driver
OLED Connector
ESP32 - MCU
Programming Header
Power Input
EEPROM

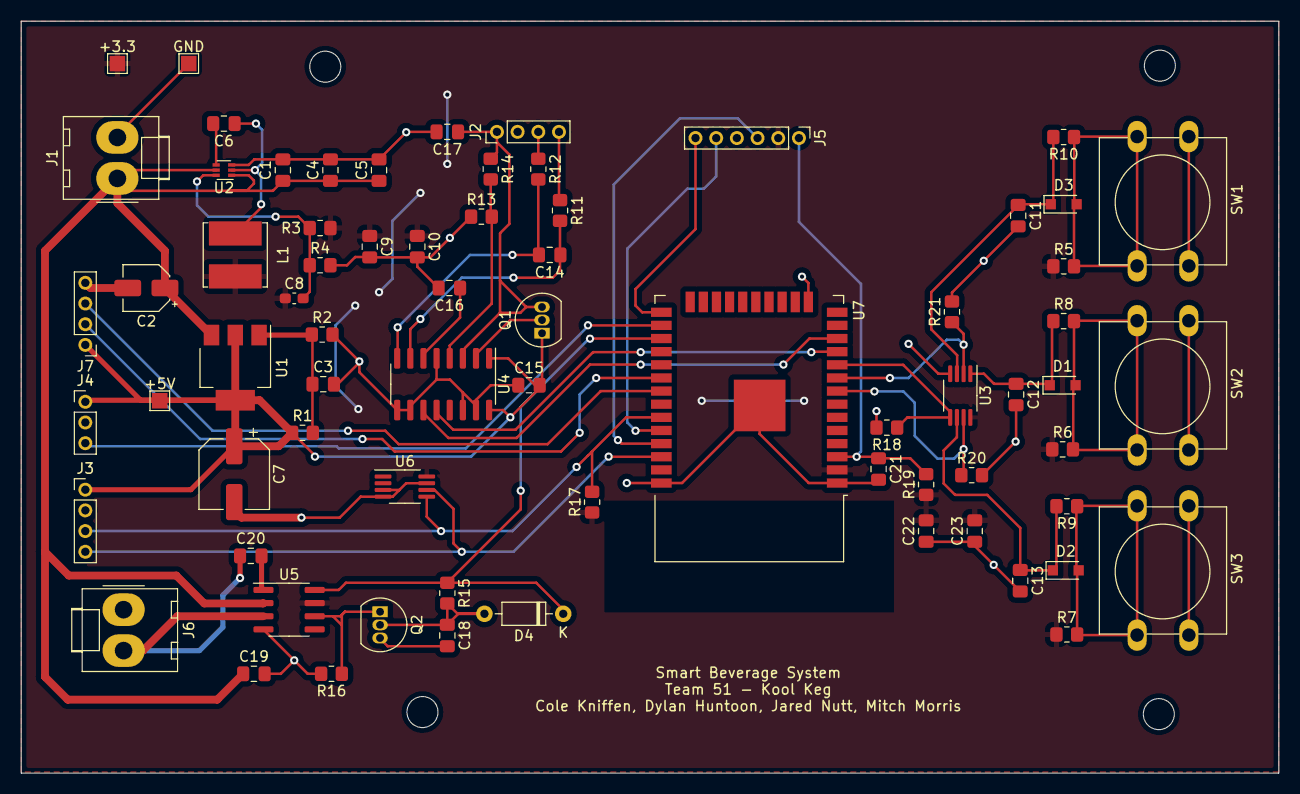
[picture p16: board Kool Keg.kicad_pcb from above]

Board: 2 copper layers, 121.6 x 72.7 mm, 71 parts (0 on the bottom side), 41 nets.

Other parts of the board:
+3.3, +5V: TestPoint_Pad_1.5x1.5mm
GND: TestPoint_Pad_1.5x1.5mm

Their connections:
+3.3V: +3.3.1; also elsewhere on the board
+5V: +5V.1; also elsewhere on the board
GND: GND.1; also elsewhere on the board

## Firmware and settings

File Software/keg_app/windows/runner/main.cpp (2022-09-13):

#include <flutter/dart_project.h>
#include <flutter/flutter_view_controller.h>
#include <windows.h>

#include "flutter_window.h"
#include "utils.h"

int APIENTRY wWinMain(_In_ HINSTANCE instance, _In_opt_ HINSTANCE prev,
                      _In_ wchar_t *command_line, _In_ int show_command) {
  // Attach to console when present (e.g., 'flutter run') or create a
  // new console when running with a debugger.
  if (!::AttachConsole(ATTACH_PARENT_PROCESS) && ::IsDebuggerPresent()) {
    CreateAndAttachConsole();
  }

  // Initialize COM, so that it is available for use in the library and/or
  // plugins.
  ::CoInitializeEx(nullptr, COINIT_APARTMENTTHREADED);

  flutter::DartProject project(L"data");

  std::vector<std::string> command_line_arguments =
      GetCommandLineArguments();

  project.set_dart_entrypoint_arguments(std::move(command_line_arguments));

  FlutterWindow window(project);
  Win32Window::Point origin(10, 10);
  Win32Window::Size size(1280, 720);
  if (!window.CreateAndShow(L"keg_app", origin, size)) {
    return EXIT_FAILURE;
  }
  window.SetQuitOnClose(true);

  ::MSG msg;
  while (::GetMessage(&msg, nullptr, 0, 0)) {
    ::TranslateMessage(&msg);
    ::DispatchMessage(&msg);
  }

  ::CoUninitialize();
  return EXIT_SUCCESS;
}

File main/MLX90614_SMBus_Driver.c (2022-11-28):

#include "driver/i2c.h"
#include "esp_log.h"
#include "MLX90614_SMBus_Driver.h"
#include <stdio.h>
#include "freertos/FreeRTOS.h"
#include "freertos/task.h"
#include "esp_system.h"
#include "esp_spi_flash.h"
#include "driver/gpio.h"
#include "sdkconfig.h"
#include <stdlib.h>
#include <string.h>
#include <inttypes.h>


#define I2C_MASTER_TX_BUF_DISABLE 0 /*!< I2C master doesn't need buffer */
#define I2C_MASTER_RX_BUF_DISABLE 0 /*!< I2C master doesn't need buffer */
#define WRITE_BIT I2C_MASTER_WRITE  /*!< I2C master write */
#define READ_BIT I2C_MASTER_READ    /*!< I2C master read */
#define ACK_CHECK_EN 0x1            /*!< I2C master will check ack from slave*/
#define ACK_CHECK_DIS 0x0           /*!< I2C master will not check ack from slave */
#define ACK_VAL 0x0                 /*!< I2C ack value */
#define NACK_VAL 0x1                /*!< I2C nack value */

uint8_t sda;
uint8_t scl;
static const char *TAG = "MLX90614_Module";
uint8_t Calculate_PEC(uint8_t, uint8_t);
void WaitEE(uint16_t ms);

void MLX90614_SMBusInit(uint8_t sda_gpio, uint8_t scl_gpio, int freq){
    sda = sda_gpio;
    scl = scl_gpio;
    i2c_config_t MLX90614_config = {
        .mode = I2C_MODE_MASTER,       /*!< I2C mode */
        .sda_io_num = sda_gpio,        /*!< GPIO number for I2C sda signal */
        .sda_pullup_en = GPIO_PULLUP_ENABLE,  /*!< Internal GPIO pull mode for I2C sda signal*/
        .scl_io_num = scl_gpio,       /*!< GPIO number for I2C scl signal */
        .scl_pullup_en = GPIO_PULLUP_ENABLE,  /*!< Internal GPIO pull mode for I2C scl signal*/
        .master.clk_speed = freq    /*!< I2C clock frequency for master mode, (no higher than 1MHz for now) */
    };
    i2c_param_config(I2C_NUM_0, &MLX90614_config);
    i2c_driver_install(I2C_NUM_0, I2C_MODE_MASTER, I2C_MASTER_RX_BUF_DISABLE, I2C_MASTER_TX_BUF_DISABLE, 0);
}

int MLX90614_SMBusRead(uint8_t slaveAddr, uint8_t reg_addr, uint16_t *data){

    uint8_t chip_addr;
    uint8_t data_addr;
    uint8_t pec;
    uint16_t *p;

    p = data;
    chip_addr = (slaveAddr << 1);
    data_addr = reg_addr;
    pec = chip_addr;
    uint8_t recived_data[3] = {0,0,0};

    i2c_cmd_handle_t cmd = i2c_cmd_link_create();
    i2c_master_start(cmd);
    i2c_master_write_byte(cmd, chip_addr | WRITE_BIT, ACK_CHECK_EN);
    i2c_master_write_byte(cmd, data_addr, ACK_CHECK_EN);
    i2c_master_start(cmd);
    chip_addr = chip_addr | 0x01;
    i2c_master_write_byte(cmd, chip_addr | READ_BIT, ACK_CHECK_EN);
    i2c_master_read(cmd, recived_data, 2, ACK_VAL);
    i2c_master_read_byte(cmd, recived_data + 2, NACK_VAL);
    i2c_master_stop(cmd);
    esp_err_t ret = i2c_master_cmd_begin(I2C_NUM_0, cmd, 1000);
    i2c_cmd_link_delete(cmd);
    if (ret == ESP_OK) {
        pec = Calculate_PEC(0, pec);
        pec = Calculate_PEC(pec, data_addr);
        pec = Calculate_PEC(pec, chip_addr);
        pec = Calculate_PEC(pec, recived_data[0]);
        pec = Calculate_PEC(pec, recived_data[1]);
    } else if (ret == ESP_ERR_TIMEOUT) {
        ESP_LOGW(TAG, "Bus is busy");
    } else {
        ESP_LOGW(TAG, "Read failed");
    }
    if (pec != recived_data[2])
    {
        return -2;
    }

    *p = (uint16_t)recived_data[1]*256 + (uint16_t)recived_data[0];
    return 0;
}

int MLX90614_SMBusWrite(uint8_t slaveAddr, uint8_t writeAddress, uint16_t data)
{
    uint8_t chip_addr;
    uint8_t send_data[4] = {0,0,0,0};
    static uint16_t dataCheck;
    uint8_t pec;

    chip_addr = (slaveAddr << 1);
    send_data[0] = writeAddress;
    send_data[1] = data & 0x00FF;
    send_data[2] = data >> 8;

    pec = Calculate_PEC(0, chip_addr);
    pec = Calculate_PEC(pec, send_data[0]);
    pec = Calculate_PEC(pec, send_data[1]);
    pec = Calculate_PEC(pec, send_data[2]);

    send_data[3] = pec;

    i2c_cmd_handle_t cmd = i2c_cmd_link_create();
    i2c_master_start(cmd);
    i2c_master_write_byte(cmd, chip_addr | WRITE_BIT, ACK_CHECK_EN);
    for (int i = 0; i < 3; i++) {
        i2c_master_write_byte(cmd, send_data[i], ACK_CHECK_EN);
    }
    i2c_master_stop(cmd);
    esp_err_t ret = i2c_master_cmd_begin(I2C_NUM_0, cmd, 1000);
    i2c_cmd_link_delete(cmd);
    if (ret == ESP_OK) {
        ESP_LOGI(TAG, "Write OK");
    } else if (ret == ESP_ERR_TIMEOUT) {
        ESP_LOGW(TAG, "Bus is busy");
    } else {
        ESP_LOGW(TAG, "Write Failed");
    }

    MLX90614_SMBusRead(slaveAddr, writeAddress, &dataCheck);

    if ( dataCheck != data)
    {
        return -3;
    }

    return 0;
}

int MLX90614_SendCommand(uint8_t slaveAddr, uint8_t command)
{
    uint8_t chip_addr;
    int ack = 0;
    uint8_t send_data[2]= {0,0};
    uint8_t pec;

    if(command != 0x60 && command != 0x61)
    {
        return -5;
    }

    chip_addr = (slaveAddr << 1);
    send_data[0] = command;

    pec = Calculate_PEC(0, chip_addr);
    pec = Calculate_PEC(pec, send_data[0]);

    send_data[1] = pec;

    i2c_cmd_handle_t cmd = i2c_cmd_link_create();
    i2c_master_start(cmd);
    i2c_master_write_byte(cmd, chip_addr | WRITE_BIT, ACK_CHECK_EN);
    for (int i = 0; i < 2; i++) {
        i2c_master_write_byte(cmd, send_data[i], ACK_CHECK_EN);
    }
    i2c_master_stop(cmd);
    esp_err_t ret = i2c_master_cmd_begin(I2C_NUM_0, cmd, 1000);
    i2c_cmd_link_delete(cmd);
    if (ret == ESP_OK) {
        ESP_LOGI(TAG, "Write OK");
    } else if (ret == ESP_ERR_TIMEOUT) {
        ESP_LOGW(TAG, "Bus is busy");
    } else {
        ESP_LOGW(TAG, "Write Failed");
    }

    return 0;
}

uint8_t Calculate_PEC (uint8_t initPEC, uint8_t newData)
{
    uint8_t data;
    uint8_t bitCheck;

    data = initPEC ^ newData;

    for (int i=0; i<8; i++ )
    {
        bitCheck = data & 0x80;
        data = data << 1;

        if (bitCheck != 0)
        {
            data = data ^ 0x07;
        }

    }
    return data;
}

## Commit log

2022-09-22 Creating combined schem
    [Circuit Design.kicad_pcb, Circuit Design.kicad_sch, power.kicad_sch]
2022-09-22 Power Sche
    [Circuit Design.kicad_sch, power.kicad_sch]
2022-09-22 Adding MCU blank sheet and
    [Circuit Design.kicad_sch, MCU.kicad_sch, power.kicad_sch]
2022-09-29 update sensors
    [Circuit Design.kicad_sch, power.kicad_sch]
2022-09-29 added function and in-line documentation
    [Circuit Design.kicad_sch, power.kicad_sch]
2022-10-13 Creating hierarch. schem. with combined subsystems
    [Circuit Design.kicad_sch, Kool Keg.kicad_pcb, Kool Keg.kicad_sch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]
2022-10-13 Rename Top Schmatic.kicad_sch to Updated_Power.kicad_sch
    [Updated_Power.kicad_sch]
2022-10-13 adding aws keys
    [Circuit Design.kicad_pcb, Circuit Design.kicad_sch, MCU.kicad_sch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]
2022-10-13 Consolidating yet again
    [Kool Keg.kicad_sch, Updated_Power.kicad_sch, power.kicad_sch]
2022-10-13 remove old KiCad project
    [Circuit Design.kicad_pcb, Circuit Design.kicad_sch, MCU.kicad_sch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]
2022-10-15 Update footprints, init layout
    [ESP32-WROOM-32D.step, Kool Keg.csv, Kool Keg.kicad_pcb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]
2022-10-17 PCB Layout
    [Kool Keg.kicad_pcb]
2022-10-20 Gerbers, ERC, DRC
    [Kool Keg-B_Cu.gbr, Kool Keg-B_Mask.gbr, Kool Keg-B_Paste.gbr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]
2022-10-20 Drill files
    [Kool Keg-B_Cu.gbr, Kool Keg-B_Mask.gbr, Kool Keg-B_Paste.gbr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]
2022-10-20 Saving pcb
    [Kool Keg.kicad_pcb]
2022-11-01 Update PCB
    [Kool Keg-B_Cu.gbr, Kool Keg-B_Mask.gbr, Kool Keg-B_Paste.gbr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]
2022-11-01 PCB update
    [Kool Keg.kicad_pcb, Kool Keg.kicad_sch, power.kicad_sch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]
2022-11-18 updated software figures
    [Kool Keg.csv]
2022-11-18 Revert "updated software figures"
    This reverts commit 1719d3f3f4208f45d1ca01678667622d50818237.
    [Kool Keg.csv]
